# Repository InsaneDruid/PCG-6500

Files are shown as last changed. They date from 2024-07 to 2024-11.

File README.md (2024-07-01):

# PCG 6500 - a HAL clone
The PCG 6500 is a 100% compatible clone of the programmable character set generator and sound device for the CBM PET series computers.
It implements all the features, including the ability to reprogram 64 of the PET characters into custom graphics, as well as support for amplified CB2 sound output.

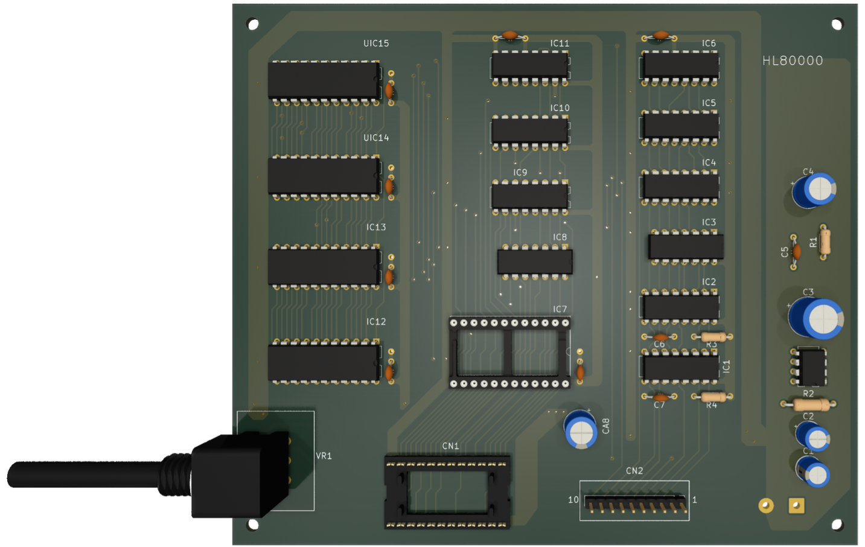
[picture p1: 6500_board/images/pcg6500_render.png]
PCG6500 render


[Schematic](https://github.com/InsaneDruid/PCG-6500/blob/main/6500_board/pcg6500.pdf "Schematic")  

[Bill of Materials](https://htmlpreview.github.io/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 "Bill of Materials")

## The 6540 Adapter
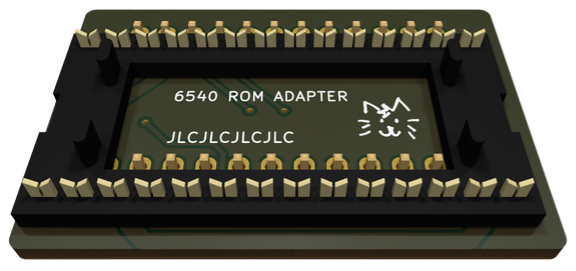
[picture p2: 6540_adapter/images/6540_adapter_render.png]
6540 Adapter render


For PETs using the MOS 6540 rom set, there is an [adapter board](https://github.com/InsaneDruid/PCG-6500/blob/main/6540_adapter "adapter board") that mounts in place of CN1 and allows easy connection to the 6540 charrom using two DIP 28pin to ribbon adapters.

## The SwitchMod
Originally, there was no way to simply disable the HAL PCG 6500 once installed. Katunori Takesita discovered a simple modification that an owner had applied to his board, which consisted of disconnecting an input of a nand-gate from address 9 of the CharROM bus (by cutting a trace) and grounding it instead, effectively disabling the RAM and re-enabling the CharROM permanently. This mod is also implemented in this replica and jumper JP1 is provided for this purpose.

### Enabling the card permanently
Bridge JP1 to permanently enable the card like it was originally.

### The SwitchMod board
A small [SwitchMod board](https://github.com/InsaneDruid/PCG-6500/blob/main/6500_switchMod "SwitchMod board") has been designed providing the ability to switch between the address9 signal and GND for the input of IC8D using an 74LS00, avoiding the need to route the fast address signal over a mechanical switch. This board also has the ability to connect a 3-pin common cathode dual LED (or one or two standard LEDs) to indicate the state of the board. Connect the pins E,A,+,- on the SwitchMod to the corresponding pins on the 6500 board.

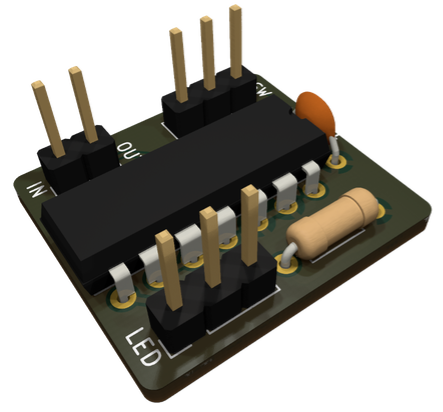
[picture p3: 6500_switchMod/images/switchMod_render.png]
SwitchMod board render


## The case
A [3d printable case](https://www.printables.com/model/819722-hal-pcg-6500-case "https://www.printables.com/model/819722-hal-pcg-6500-case") is available at my printables profile.
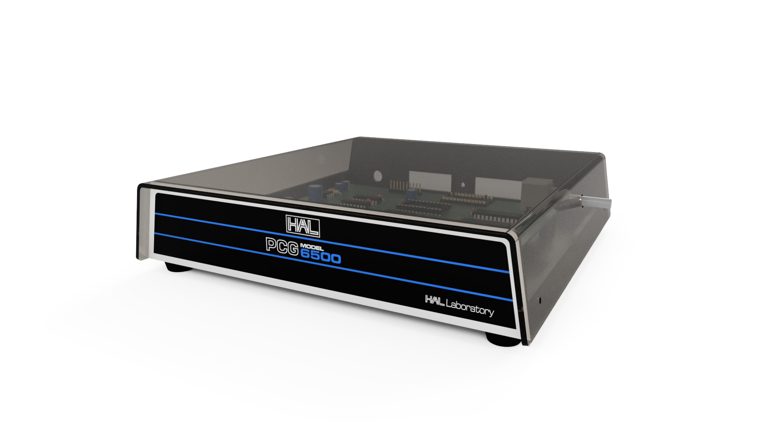
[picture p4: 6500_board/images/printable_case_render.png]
printable case render


## Programming the PCG 6500 
Each programmable character provided by the PCG 6500 is programmed line by line via the PETs 6522 peripheral port A (PA7-0), which is available on the user port. PA0-4 transport the actual data, PA 5-7 address the data and address latches on the PCG 6500
See the [Programming chart](https://github.com/InsaneDruid/PCG-6500/blob/main/6500_programming_chart.pdf "Programming chart") originally taken from the PCG 6500 manual with some fixed typos.

## The Software
Software using the PCG-6500 and further documents are available on their own repository: [PCG-6500 Software](https://github.com/InsaneDruid/PCG-6500-Software "Software and Documents for the PCG-6500 Software")

## The License
This work is licensed under a Creative Commons Attribution-ShareAlike 4.0 International License.  
See https://creativecommons.org/licenses/by-sa/4.0/.

## The Credits
This work would not have been possible without the help from a bunch of amazing people from [VzEkC e. V. forums](https://forum.classic-computing.de/forum/ "forum.classic-computing.de") and around the world. Many thanks go out to:

* *AndyG* - for providing images of a working board.
* *Katunori Takesita* - his blog about repairing an original board had important additional images and informations.

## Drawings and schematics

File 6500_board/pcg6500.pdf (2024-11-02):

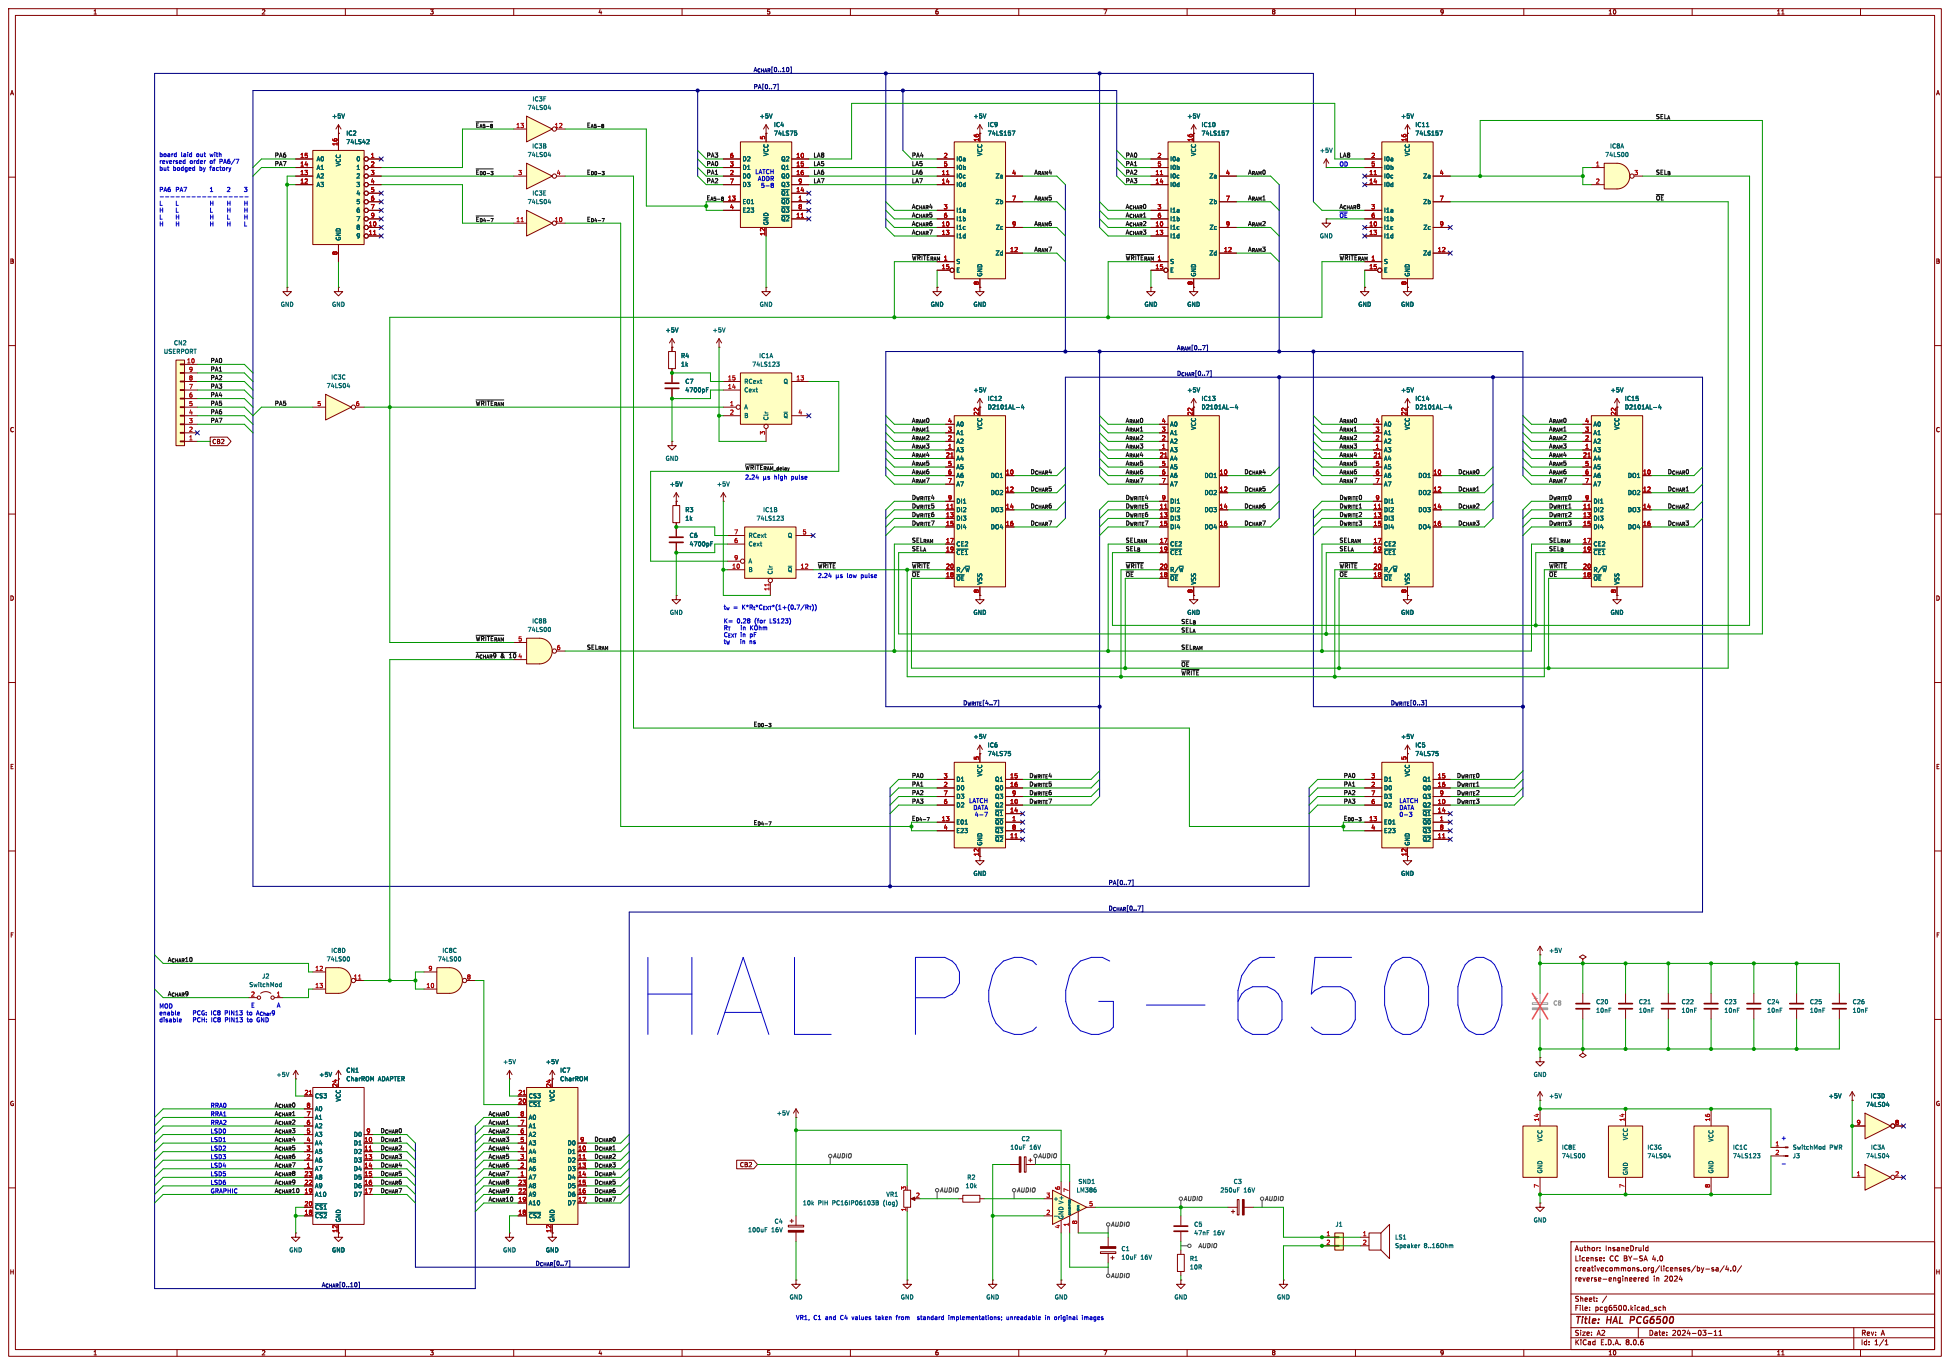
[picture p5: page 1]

board laid out with
reversed order of PA6/7

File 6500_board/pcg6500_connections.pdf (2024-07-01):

# HAL PCG-6500 wire connections

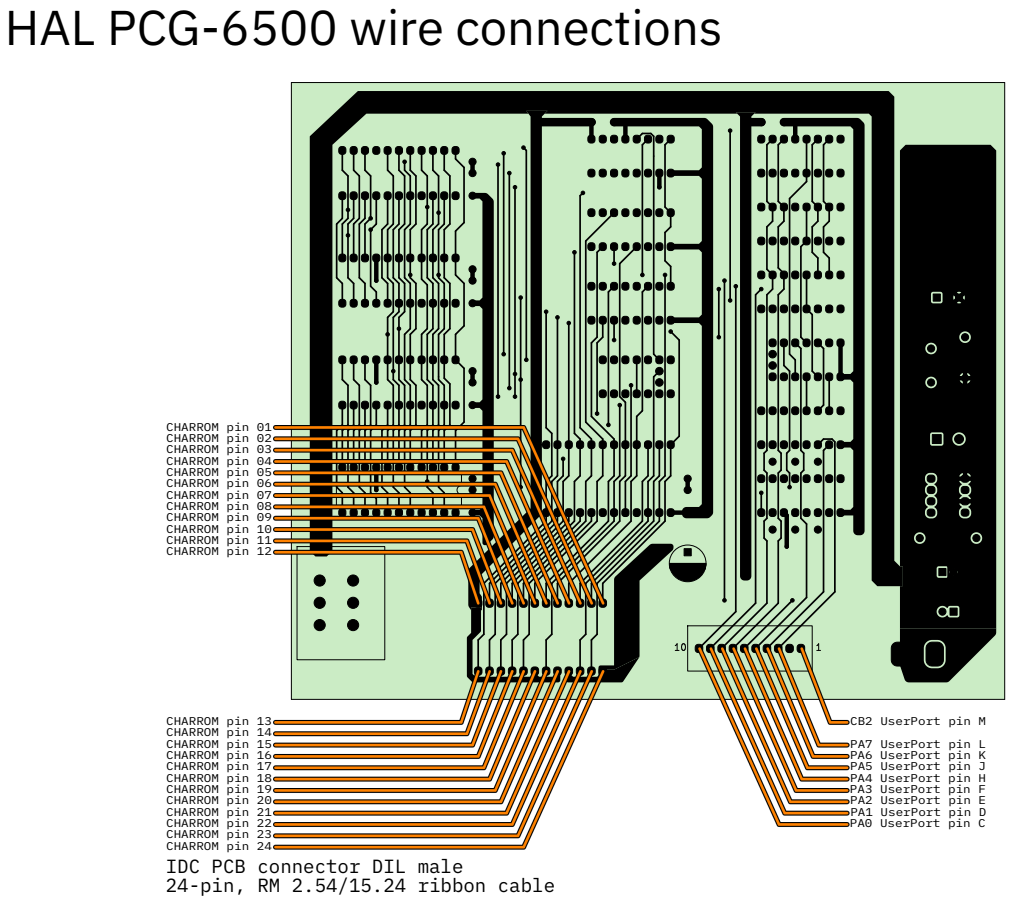
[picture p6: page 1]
CHARROM pin 12; CHARROM pin 11; CHARROM pin 10; CHARROM pin 08; CHARROM pin 07; CHARROM pin 06; CHARROM pin 05; CHARROM pin 04; CHARROM pin 03; CHARROM pin 02; CHARROM pin 01; CHARROM pin 09; PA0 UserPort pin C; PA1 UserPort pin D; PA2 UserPort pin E; PA4 UserPort pin H; PA5 UserPort pin J; PA6 UserPort pin K; PA7 UserPort pin L; CB2 UserPort pin M; PA3 UserPort pin F

CHARROM pin 13
CHARROM pin 14
CHARROM pin 15
CHARROM pin 16
CHARROM pin 17
CHARROM pin 18
CHARROM pin 19
CHARROM pin 20
CHARROM pin 21
CHARROM pin 22
CHARROM pin 23
CHARROM pin 24
IDC PCB connector DIL male
24-pin, RM 2.54/15.24 ribbon cable

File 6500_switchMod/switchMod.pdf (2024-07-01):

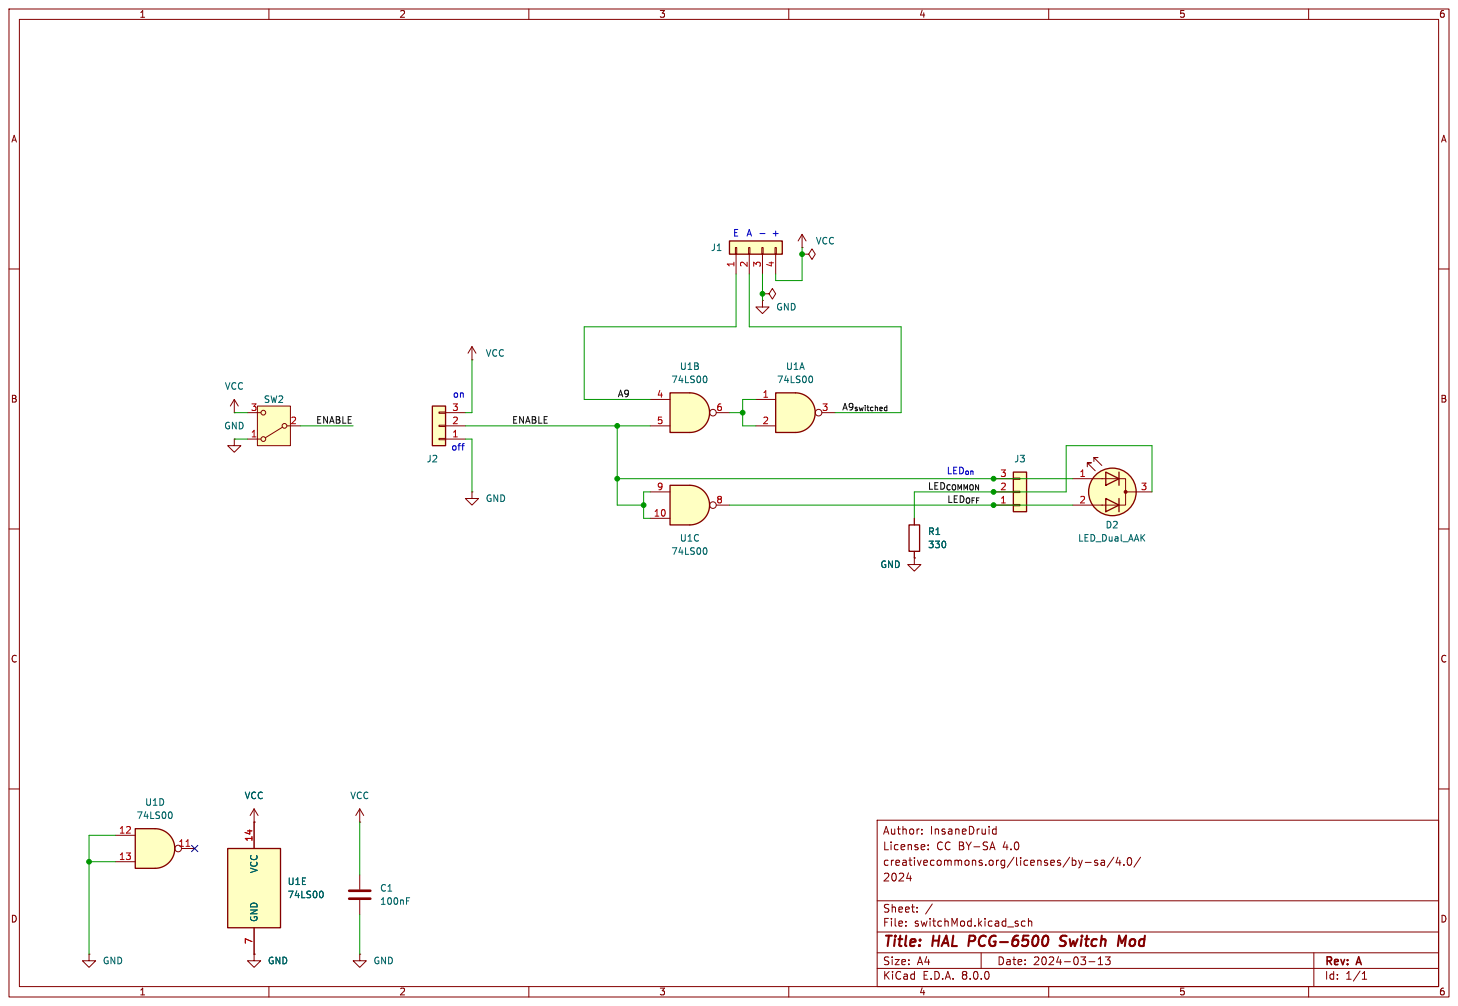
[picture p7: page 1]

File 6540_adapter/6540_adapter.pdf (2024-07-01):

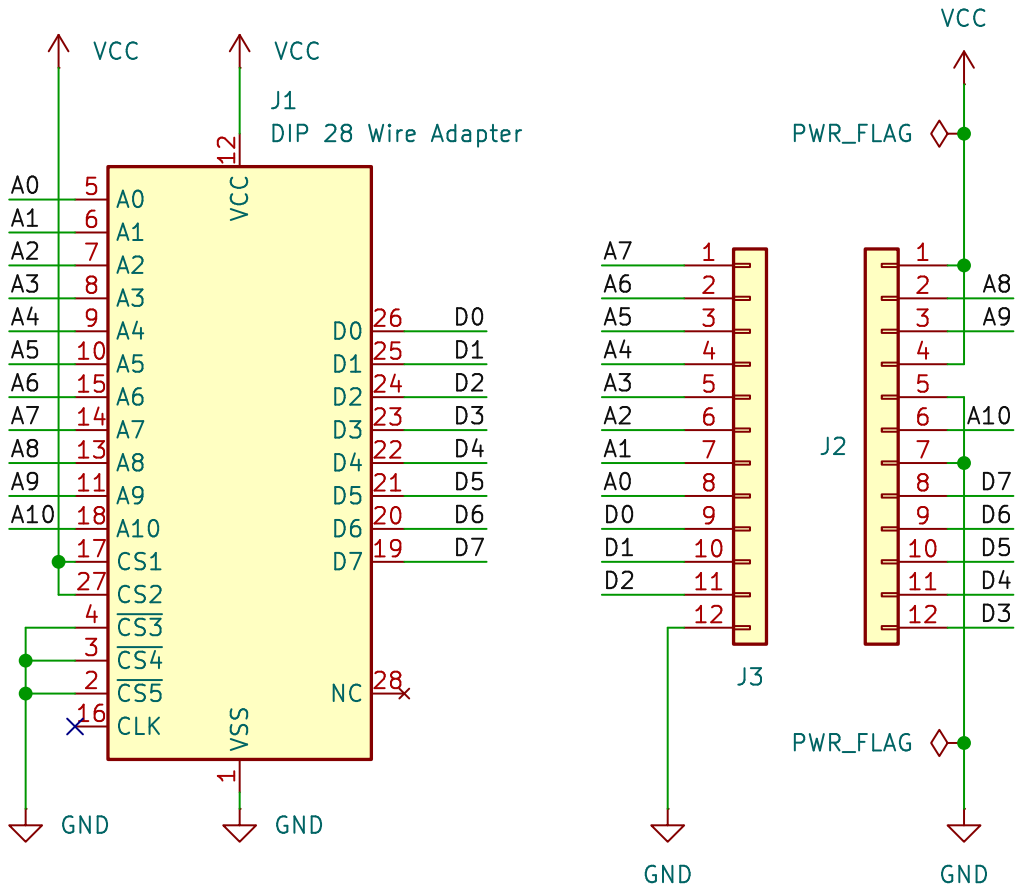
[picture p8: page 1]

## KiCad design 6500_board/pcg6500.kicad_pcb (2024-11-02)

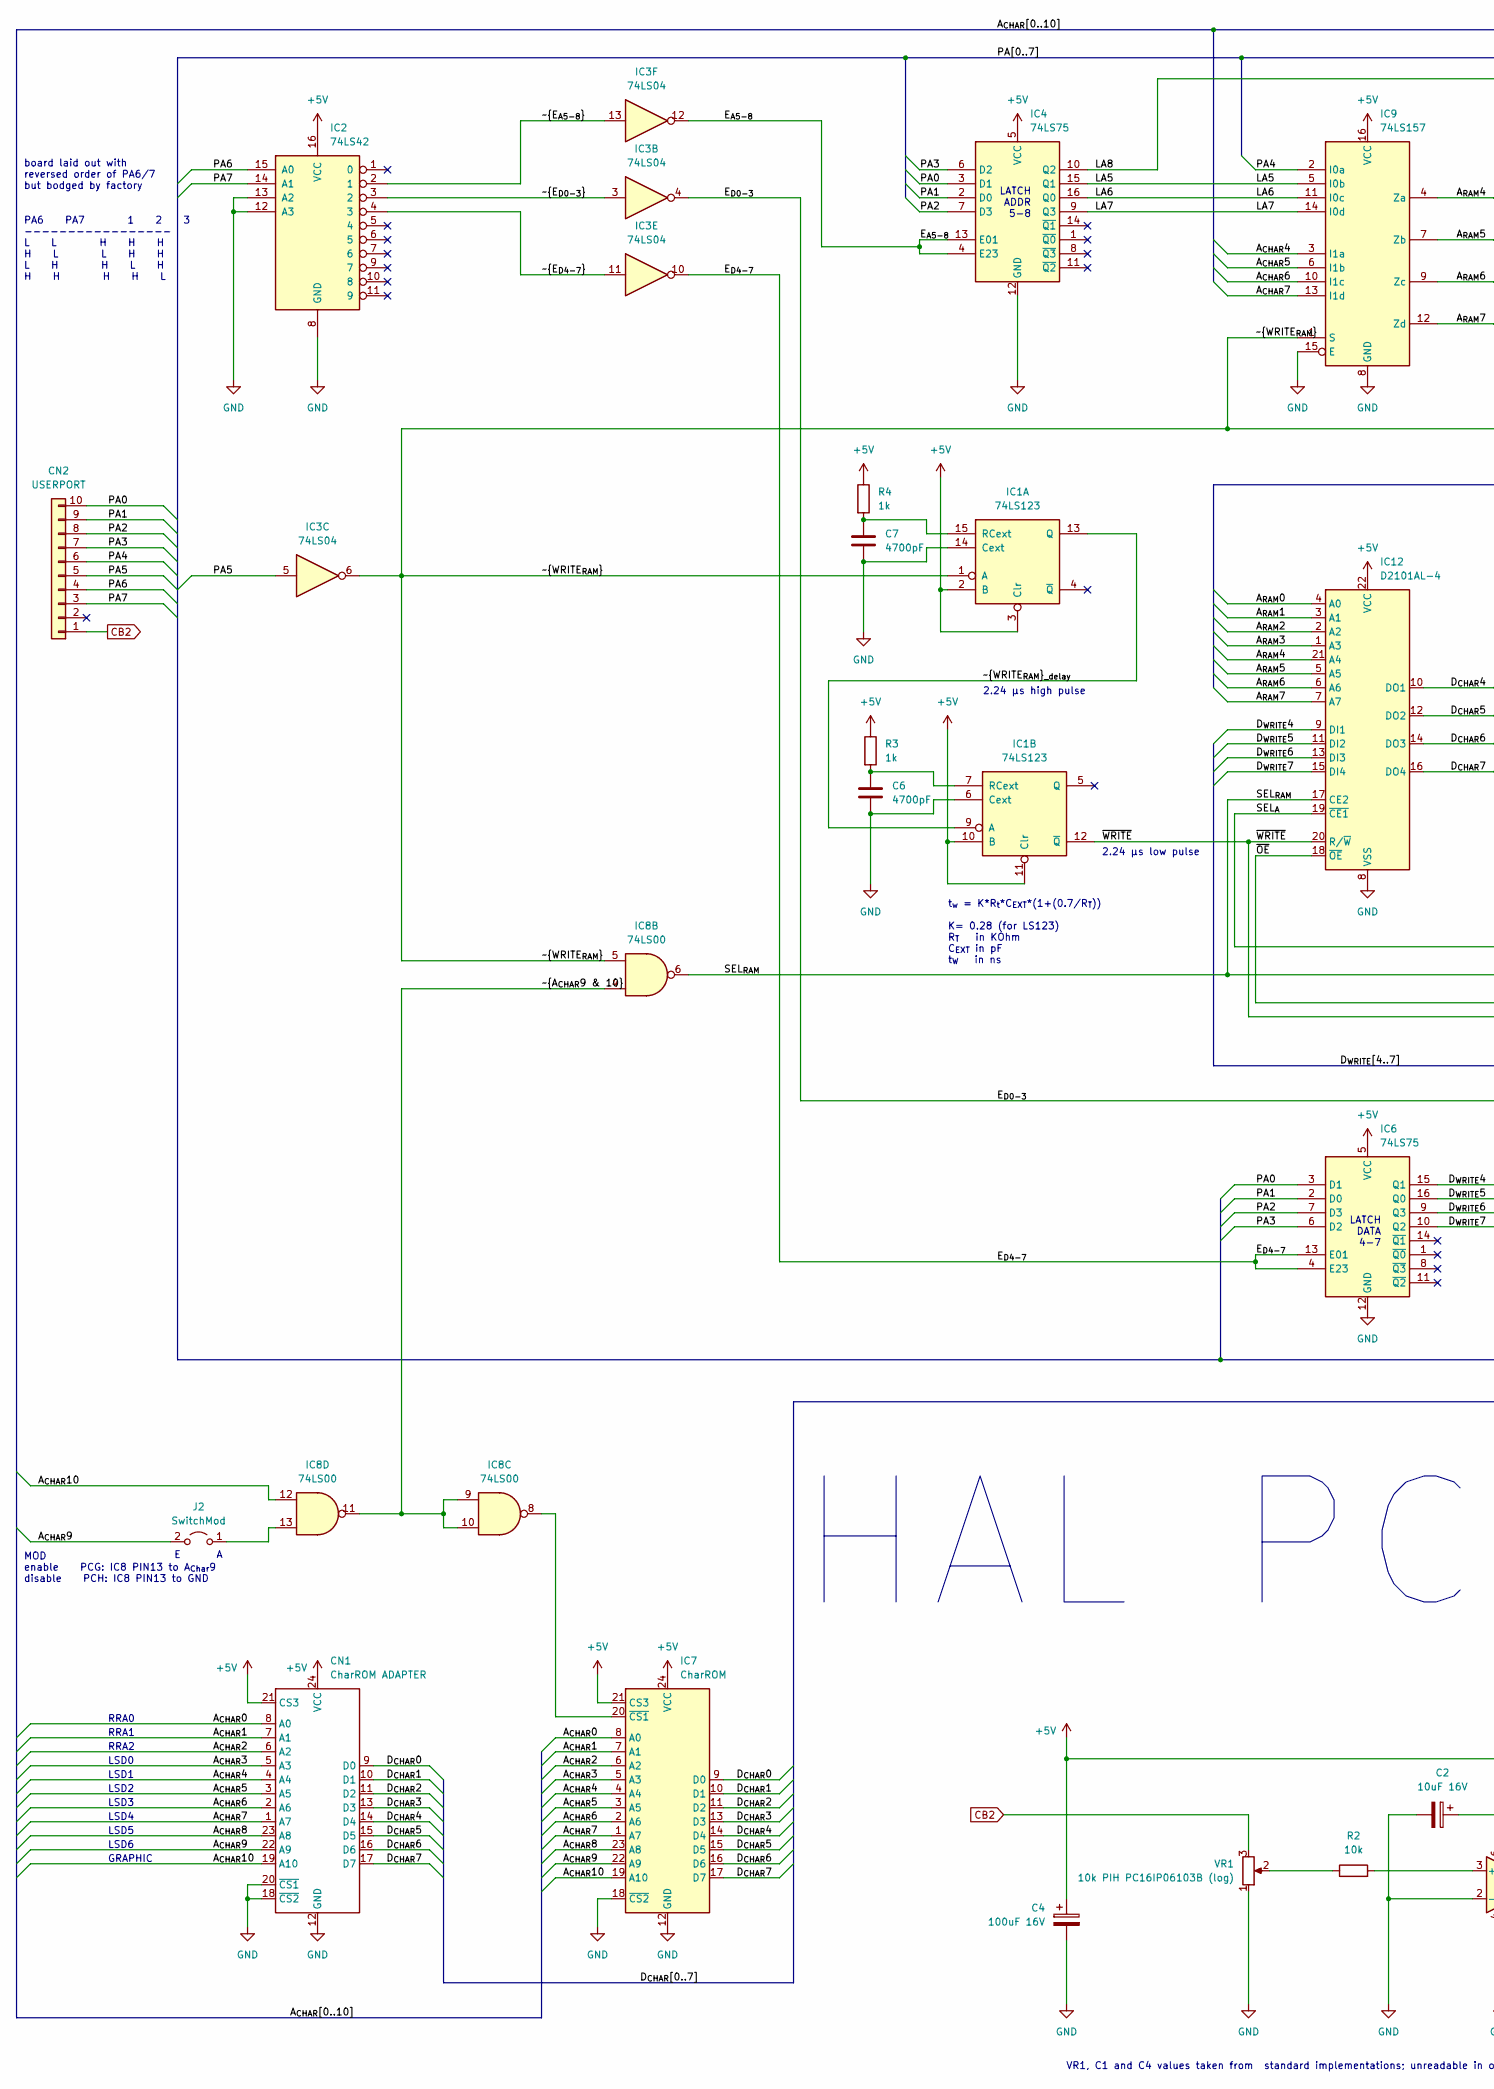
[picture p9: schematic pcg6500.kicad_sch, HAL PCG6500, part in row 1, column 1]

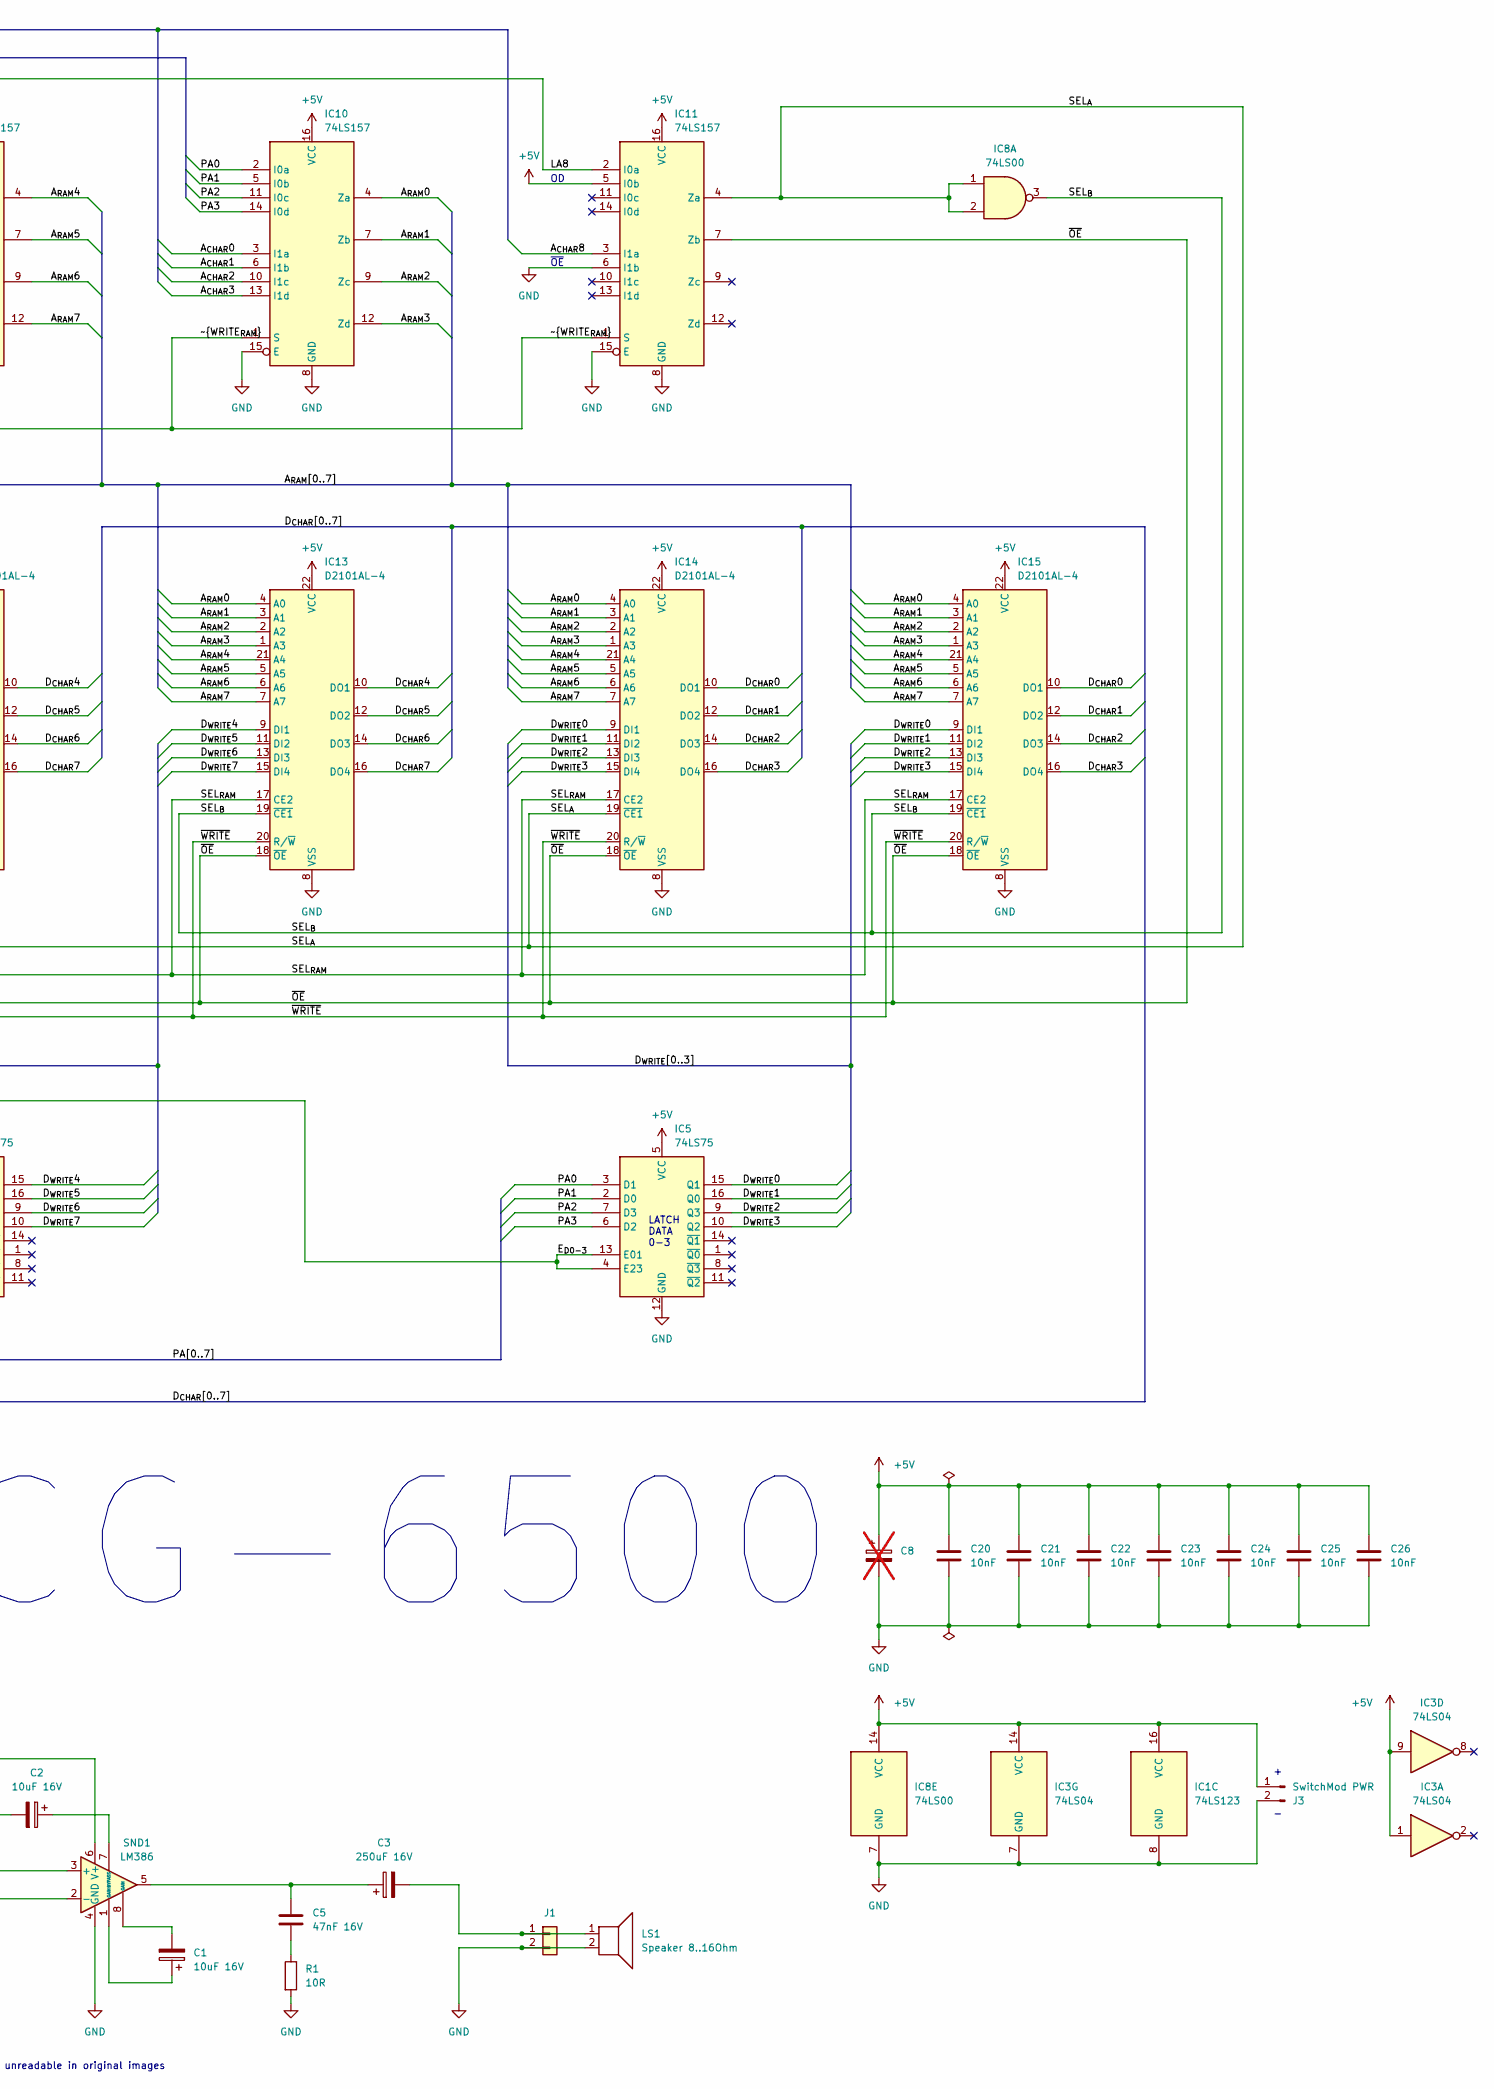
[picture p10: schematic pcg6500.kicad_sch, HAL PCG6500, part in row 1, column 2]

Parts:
C1, C2: 10uF 16V; CP_Radial_D6.3mm_P2.50mm
C3: 250uF 16V; CP_Radial_D10.0mm_P5.00mm
C4: 100uF 16V; CP_Radial_D8.0mm_P5.00mm
C5: 47nF 16V; C_Disc_D4.3mm_W1.9mm_P7.62mm
C6, C7: 4700pF; C_Disc_D4.3mm_W1.9mm_P5.08mm
C8: C_Polarized; CP_Radial_D8.0mm_P5.00mm; not fitted
C20, C21, C22, C23, C24, C25, C26: 10nF; C_Disc_D4.3mm_W1.9mm_P5.08mm_dualpad
CN1: CharROM ADAPTER; DIP-24_W15.24mm_Wire_Adapter
CN2: USERPORT; PinHeader_1x10_P2.54mm_Vertical
IC1: 74LS123; DIP-16_W7.62mm
IC2: 74LS42; DIP-16_W7.62mm
IC3: 74LS04; DIP-14_W7.62mm
IC4, IC5, IC6: 74LS75; DIP-16_W7.62mm
IC7: CharROM; DIP-24_W15.24mm_Socket
IC8: 74LS00; DIP-14_W7.62mm
IC9, IC10, IC11: 74LS157; DIP-16_W7.62mm
IC12, IC13, IC14, IC15: D2101AL-4; DIP-22_W10.16mm
J1: Speaker 8..16Ohm; SolderWire-1sqmm_1x02_P7.8mm_D1.4mm_OD3.9mm
J2: SwitchMod; PinHeader_1x02_P2.54mm_Horizontal
J3: SwitchMod PWR; PinHeader_1x02_P2.54mm_Horizontal
LS1: Speaker 8..16Ohm
R1: 10R; R_Axial_DIN0207_L6.3mm_D2.5mm_P9.2075mm_Horizontal
R2: 10k; R_Axial_DIN0309_L9.0mm_D3.2mm_P12.70mm_Horizontal
R3, R4: 1k; R_Axial_DIN0207_L6.3mm_D2.5mm_P9.2075mm_Horizontal
SND1: LM386; DIP-8_W7.62mm
VR1: 10k PIH PC16IP06103B (log); Potentiometer_Piher_PC-16_Dual_Horizontal

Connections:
+5V: C4.1, C8.1, C20.1, C21.1, C22.1, C23.1, C24.1, C25.2, C26.2, CN1.21 (CS3), CN1.24 (VCC), IC1.2 (B), IC1.3 (Clr), IC1.10 (B), IC1.11 (Clr), IC1.16 (VCC), IC2.16 (VCC), IC3.1, IC3.9, IC3.14 (VCC), IC4.5 (VCC), IC5.5 (VCC), IC6.5 (VCC), IC7.21 (CS3), IC7.24 (VCC), IC8.14 (VCC), IC9.16 (VCC), IC10.16 (VCC), IC11.5 (I0b), IC11.16 (VCC), IC12.22 (VCC), IC13.22 (VCC), IC14.22 (VCC), IC15.22 (VCC), J3.1, R3.1, R4.1, SND1.6 (V+)
/A_{CHAR}0: CN1.8 (A0), IC7.8 (A0), IC10.3 (I1a)
/A_{CHAR}1: CN1.7 (A1), IC7.7 (A1), IC10.6 (I1b)
/A_{CHAR}2: CN1.6 (A2), IC7.6 (A2), IC10.10 (I1c)
/A_{CHAR}3: CN1.5 (A3), IC7.5 (A3), IC10.13 (I1d)
/A_{CHAR}4: CN1.4 (A4), IC7.4 (A4), IC9.3 (I1a)
/A_{CHAR}5: CN1.3 (A5), IC7.3 (A5), IC9.6 (I1b)
/A_{CHAR}6: CN1.2 (A6), IC7.2 (A6), IC9.10 (I1c)
/A_{CHAR}7: CN1.1 (A7), IC7.1 (A7), IC9.13 (I1d)
/A_{CHAR}8: CN1.23 (A8), IC7.23 (A8), IC11.3 (I1a)
/A_{CHAR}9: CN1.22 (A9), IC7.22 (A9), J2.2 (B)
/A_{CHAR}10: CN1.19 (A10), IC7.19 (A10), IC8.12
/A_{RAM}0: IC10.4 (Za), IC12.4 (A0), IC13.4 (A0), IC14.4 (A0), IC15.4 (A0)
/A_{RAM}1: IC10.7 (Zb), IC12.3 (A1), IC13.3 (A1), IC14.3 (A1), IC15.3 (A1)
/A_{RAM}2: IC10.9 (Zc), IC12.2 (A2), IC13.2 (A2), IC14.2 (A2), IC15.2 (A2)
/A_{RAM}3: IC10.12 (Zd), IC12.1 (A3), IC13.1 (A3), IC14.1 (A3), IC15.1 (A3)
/A_{RAM}4: IC9.4 (Za), IC12.21 (A4), IC13.21 (A4), IC14.21 (A4), IC15.21 (A4)
/A_{RAM}5: IC9.7 (Zb), IC12.5 (A5), IC13.5 (A5), IC14.5 (A5), IC15.5 (A5)
/A_{RAM}6: IC9.9 (Zc), IC12.6 (A6), IC13.6 (A6), IC14.6 (A6), IC15.6 (A6)
/A_{RAM}7: IC9.12 (Zd), IC12.7 (A7), IC13.7 (A7), IC14.7 (A7), IC15.7 (A7)
/D_{CHAR}0: CN1.9 (D0), IC7.9 (D0), IC14.10 (DO1), IC15.10 (DO1)
/D_{CHAR}1: CN1.10 (D1), IC7.10 (D1), IC14.12 (DO2), IC15.12 (DO2)
/D_{CHAR}2: CN1.11 (D2), IC7.11 (D2), IC14.14 (DO3), IC15.14 (DO3)
/D_{CHAR}3: CN1.13 (D3), IC7.13 (D3), IC14.16 (DO4), IC15.16 (DO4)
/D_{CHAR}4: CN1.14 (D4), IC7.14 (D4), IC12.10 (DO1), IC13.10 (DO1)
/D_{CHAR}5: CN1.15 (D5), IC7.15 (D5), IC12.12 (DO2), IC13.12 (DO2)
/D_{CHAR}6: CN1.16 (D6), IC7.16 (D6), IC12.14 (DO3), IC13.14 (DO3)
/D_{CHAR}7: CN1.17 (D7), IC7.17 (D7), IC12.16 (DO4), IC13.16 (DO4)
/D_{WRITE}0: IC5.15 (Q1), IC14.9 (DI1), IC15.9 (DI1)
/D_{WRITE}1: IC5.16 (Q0), IC14.11 (DI2), IC15.11 (DI2)
/D_{WRITE}2: IC5.9 (Q3), IC14.13 (DI3), IC15.13 (DI3)
/D_{WRITE}3: IC5.10 (Q2), IC14.15 (DI4), IC15.15 (DI4)
/D_{WRITE}4: IC6.15 (Q1), IC12.9 (DI1), IC13.9 (DI1)
/D_{WRITE}5: IC6.16 (Q0), IC12.11 (DI2), IC13.11 (DI2)
/D_{WRITE}6: IC6.9 (Q3), IC12.13 (DI3), IC13.13 (DI3)
/D_{WRITE}7: IC6.10 (Q2), IC12.15 (DI4), IC13.15 (DI4)
/E_{A5-8}: IC3.12, IC4.4 (E23), IC4.13 (E01)
/E_{D0-3}: IC3.4, IC5.4 (E23), IC5.13 (E01)
/E_{D4-7}: IC3.10, IC6.4 (E23), IC6.13 (E01)
/LA5: IC4.15 (Q1), IC9.5 (I0b)
/LA6: IC4.16 (Q0), IC9.11 (I0c)
/LA7: IC4.9 (Q3), IC9.14 (I0d)
/LA8: IC4.10 (Q2), IC11.2 (I0a)
/PA0: CN2.10, IC4.3 (D1), IC5.3 (D1), IC6.3 (D1), IC10.2 (I0a)
/PA1: CN2.9, IC4.2 (D0), IC5.2 (D0), IC6.2 (D0), IC10.5 (I0b)
/PA2: CN2.8, IC4.7 (D3), IC5.7 (D3), IC6.7 (D3), IC10.11 (I0c)
/PA3: CN2.7, IC4.6 (D2), IC5.6 (D2), IC6.6 (D2), IC10.14 (I0d)
/PA4: CN2.6, IC9.2 (I0a)
/PA5: CN2.5, IC3.5
/PA6: CN2.4, IC2.15 (A0)
/PA7: CN2.3, IC2.14 (A1)
/SEL_{A}: IC8.1, IC8.2, IC11.4 (Za), IC12.19 (~CE1), IC14.19 (~CE1)
/SEL_{B}: IC8.3, IC13.19 (~CE1), IC15.19 (~CE1)
/SEL_{RAM}: IC8.6, IC12.17 (CE2), IC13.17 (CE2), IC14.17 (CE2), IC15.17 (CE2)
/~A_{CHAR9 & 10}: IC8.4, IC8.9, IC8.10, IC8.11
/~E_{A5-8}: IC2.2 (1), IC3.13
/~E_{D0-3}: IC2.3 (2), IC3.3
/~E_{D4-7}: IC2.4 (3), IC3.11
/~OE: IC11.7 (Zb), IC12.18 (~OE), IC13.18 (~OE), IC14.18 (~OE), IC15.18 (~OE)
/~WRITE_{RAM}: IC1.1 (A), IC3.6, IC8.5, IC9.1 (S), IC10.1 (S), IC11.1 (S)
/~WRITE_{RAM}_{_delay}: IC1.9 (A), IC1.13 (Q)
/~WRITE: IC1.12 (~Q), IC12.20 (R/~W), IC13.20 (R/~W), IC14.20 (R/~W), IC15.20 (R/~W)
CB2: CN2.1, VR1.3
GND: C2.2, C4.2, C6.2, C7.2, C8.2, C20.2, C21.2, C22.2, C23.2, C24.2, C25.1, C26.1, CN1.12 (GND), CN1.18 (~CS2), CN1.20 (~CS1), IC1.6 (Cext), IC1.8 (GND), IC1.14 (Cext), IC2.8 (GND), IC2.12 (A3), IC2.13 (A2), IC3.7 (GND), IC4.12 (GND), IC5.12 (GND), IC6.12 (GND), IC7.12 (GND), IC7.18 (~CS2), IC8.7 (GND), IC9.8 (GND), IC9.15 (E), IC10.8 (GND), IC10.15 (E), IC11.6 (I1b), IC11.8 (GND), IC11.15 (E), IC12.8 (VSS), IC13.8 (VSS), IC14.8 (VSS), IC15.8 (VSS), J1.2, J1.12, J1.18, J1.20, J3.2, LS1.2, R1.2, SND1.2 (-), SND1.4 (GND), VR1.1
unnamed: C1.1, SND1.1 (GAIN)
unnamed: C1.2, SND1.8 (GAIN)
unnamed: C3.1, C5.1, SND1.5
unnamed: C5.2, R1.1
unnamed: C7.1, IC1.15 (RCext), R4.2
unnamed: C6.1, IC1.7 (RCext), R3.2
unnamed: IC7.20 (~CS1), IC8.8
unnamed: C3.2, J1.1, LS1.1
unnamed: IC8.13, J2.1 (A)
unnamed: R2.1, VR1.2
unnamed: R2.2, SND1.3 (+)
unnamed: C2.1, SND1.7 (BYPASS)

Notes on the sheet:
LATCH DATA 4-7
board laid out with reversed order of PA6/7 but bodged by factory
LATCH DATA 0-3
LSD2
LATCH ADDR 5-8
2.24 µs low pulse
t_{w} = K*R_{t}*C_{EXT}*(1+(0.7/R_{T})) K= 0.28 (for LS123) R_{T} in KOhm C_{EXT} in pF t_{W} in ns
RRA2
RRA1
GRAPHIC
LSD1
RRA0
LSD0
2.24 µs high pulse
HAL PCG-6500
LSD6
LSD3
LSD5
~{OE}
MOD enable PCG: IC8 PIN13 to A_{Char}9 disable PCH: IC8 PIN13 to GND
LSD4
VR1, C1 and C4 values taken from standard implementations; unreadable in original images
PA6 PA7 1 2 3 ----------------- L L H H H H L L H H L H H L H H H H H L

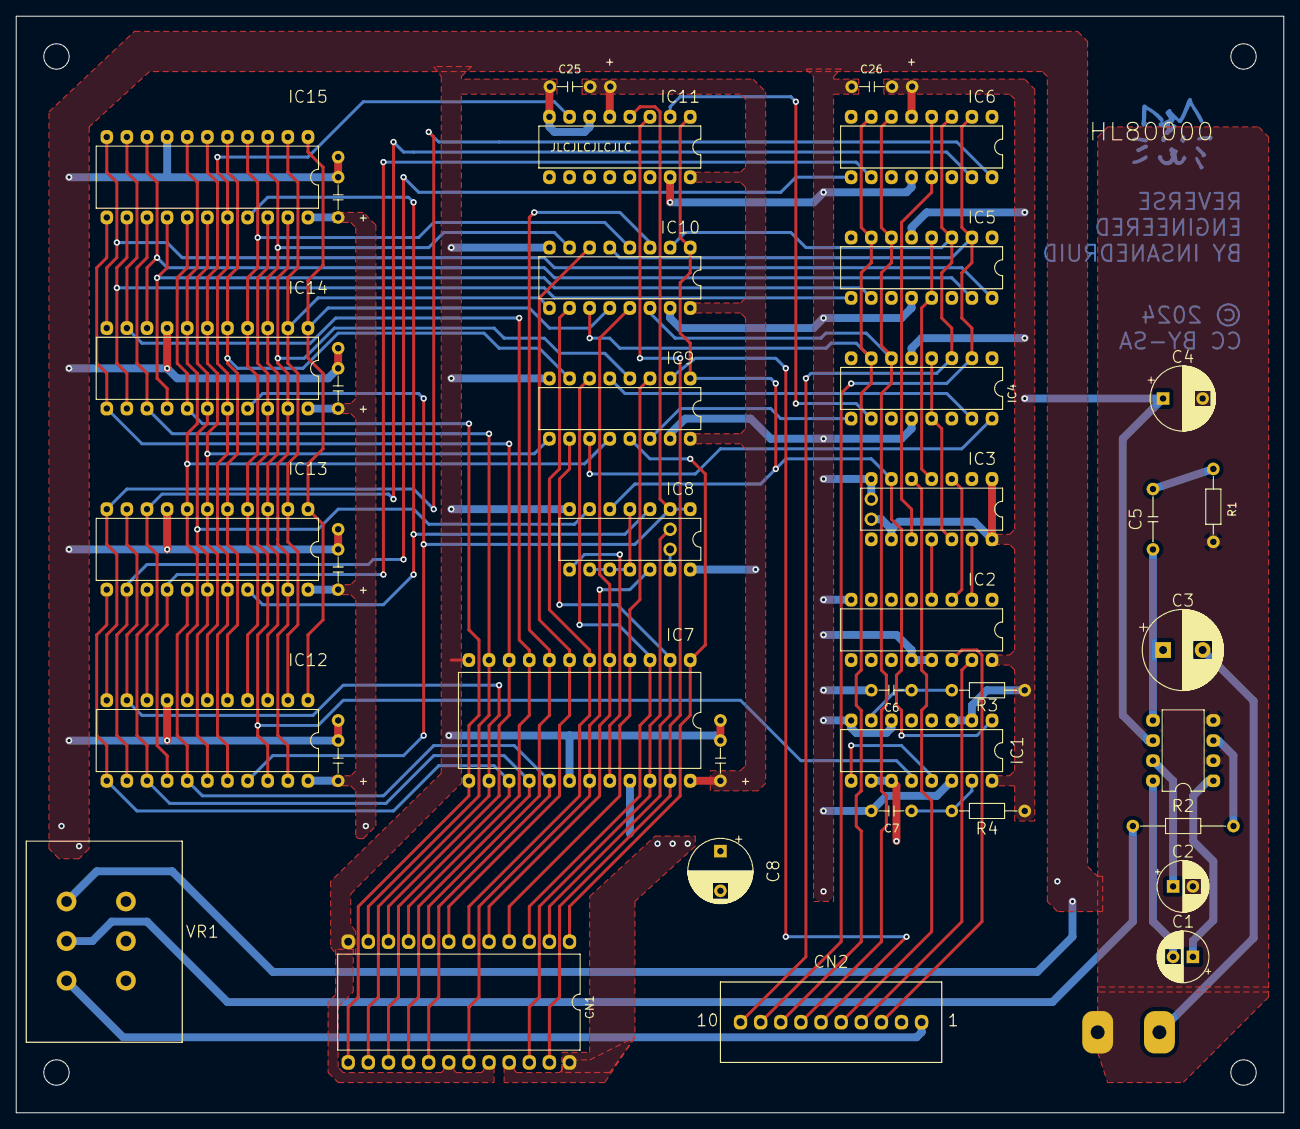
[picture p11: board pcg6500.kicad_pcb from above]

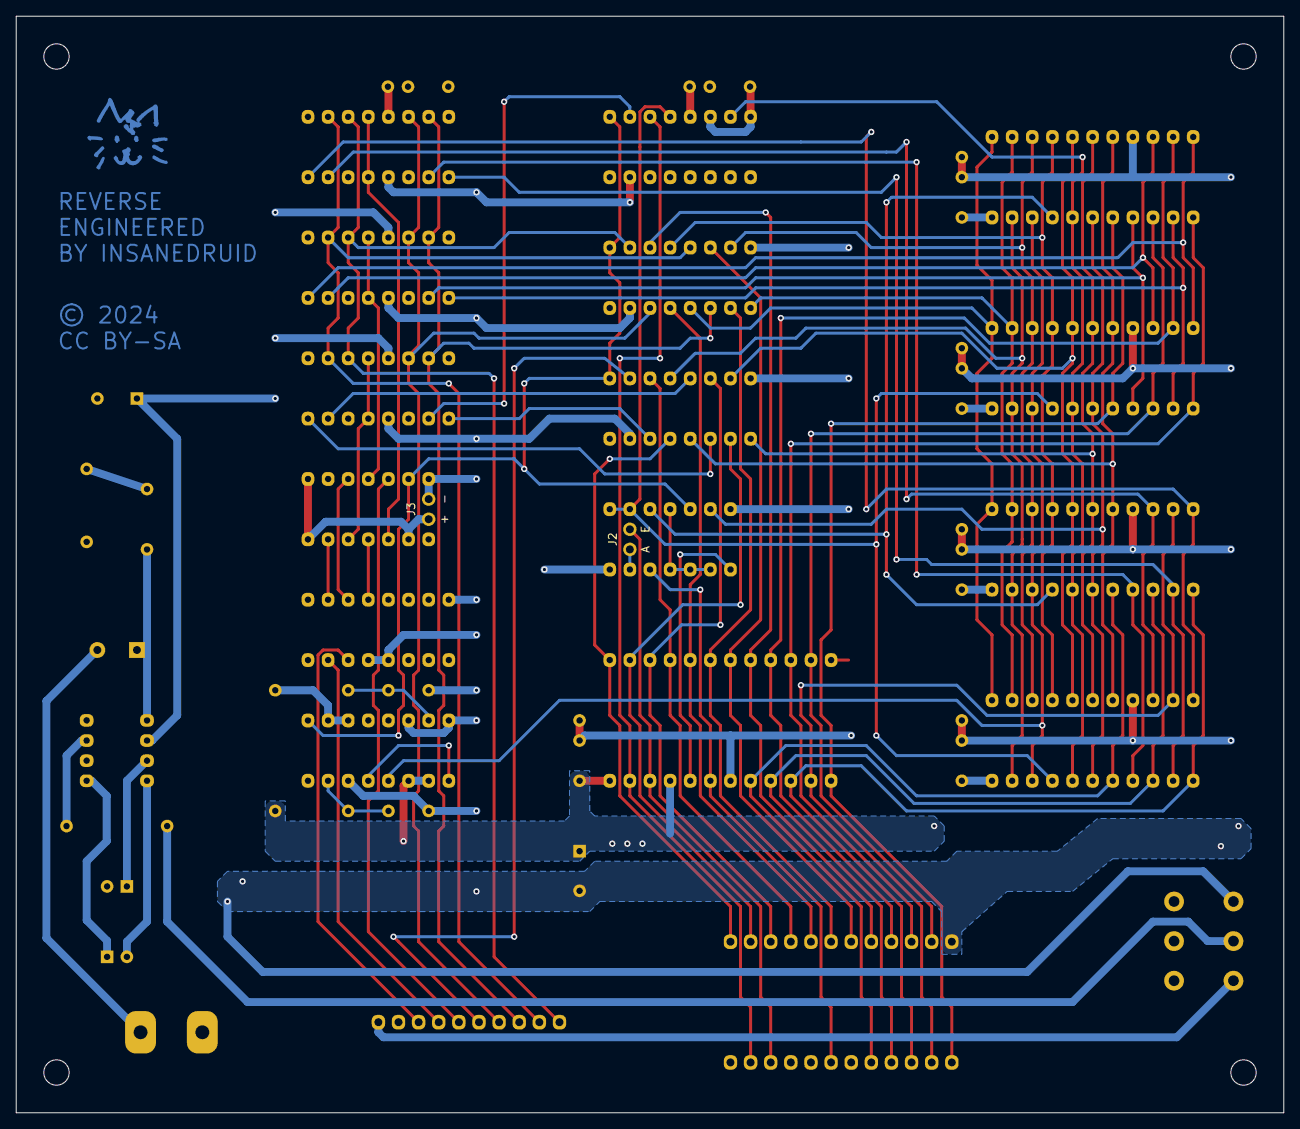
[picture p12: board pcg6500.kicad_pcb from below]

Board: 2 copper layers, 160.0 x 138.4 mm, 45 parts (2 on the bottom side), 76 nets.

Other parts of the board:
Mountinghole_BL: MountingHole_3.2mm_M3_DIN965
Mountinghole_BR: MountingHole_3.2mm_M3_DIN965
Mountinghole_TL: MountingHole_3.2mm_M3_DIN965
Mountinghole_TR: MountingHole_3.2mm_M3_DIN965

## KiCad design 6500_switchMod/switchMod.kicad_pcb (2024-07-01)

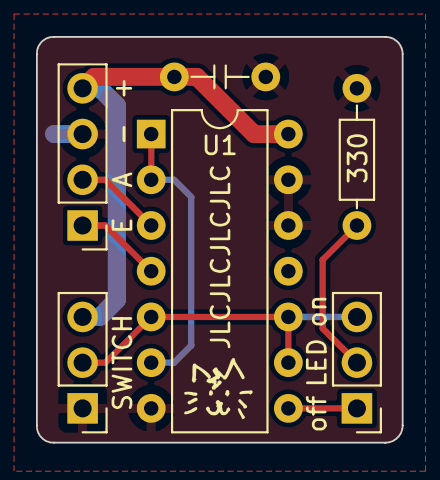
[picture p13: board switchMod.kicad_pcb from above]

Board: 2 copper layers, 20.3 x 22.5 mm, 6 parts (0 on the bottom side), 8 nets.

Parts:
C1: 100nF; C_Disc_D4.3mm_W1.9mm_P5.08mm
J1: 6500 Connector; PinHeader_1x04_P2.54mm_Vertical
J2: Switch Connector; PinHeader_1x03_P2.54mm_Vertical
J3: LED Connector; PinHeader_1x03_P2.54mm_Vertical
R1: 330R; R_Axial_DIN0207_L6.3mm_D2.5mm_P7.62mm_Horizontal
U1: 74LS00; DIP-14_W7.62mm

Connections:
/A9: J1.1, U1.4
/A9_{switched}: J1.2, U1.3
/ENABLE: J2.2, J3.3, U1.5, U1.9, U1.10
/LED_{COMMON}: J3.2, R1.2
/LED_{OFF}: J3.1, U1.8
GND: C1.2, J1.3, J2.1, R1.1, U1.7 (GND), U1.12, U1.13
unnamed: U1.1, U1.2, U1.6
VCC: C1.1, J1.4, J2.3, U1.14 (VCC)

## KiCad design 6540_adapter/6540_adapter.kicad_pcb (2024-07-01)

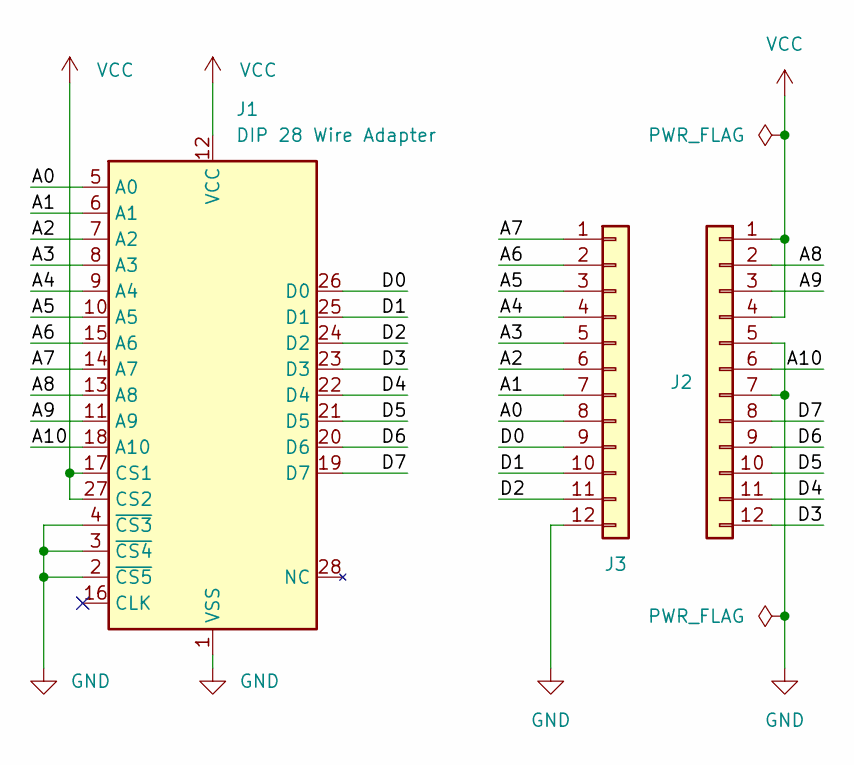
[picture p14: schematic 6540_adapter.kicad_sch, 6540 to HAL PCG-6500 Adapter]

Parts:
J1: DIP 28 Wire Adapter; DIP-28_W15.24mm_Wire_Adapter
J2, J3: Conn_01x12; PinHeader_1x12_P2.54mm_Vertical

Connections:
/A0: J1.5 (A0), J3.8
/A1: J1.6 (A1), J3.7
/A2: J1.7 (A2), J3.6
/A3: J1.8 (A3), J3.5
/A4: J1.9 (A4), J3.4
/A5: J1.10 (A5), J3.3
/A6: J1.15 (A6), J3.2
/A7: J1.14 (A7), J3.1
/A8: J1.13 (A8), J2.2
/A9: J1.11 (A9), J2.3
/A10: J1.18 (A10), J2.6
/D0: J1.26 (D0), J3.9
/D1: J1.25 (D1), J3.10
/D2: J1.24 (D2), J3.11
/D3: J1.23 (D3), J2.12
/D4: J1.22 (D4), J2.11
/D5: J1.21 (D5), J2.10
/D6: J1.20 (D6), J2.9
/D7: J1.19 (D7), J2.8
GND: J1.1 (VSS), J1.2 (~CS5), J1.3 (~CS4), J1.4 (~CS3), J2.5, J2.7, J3.12
VCC: J1.12 (VCC), J1.17 (CS1), J1.27 (CS2), J2.1, J2.4

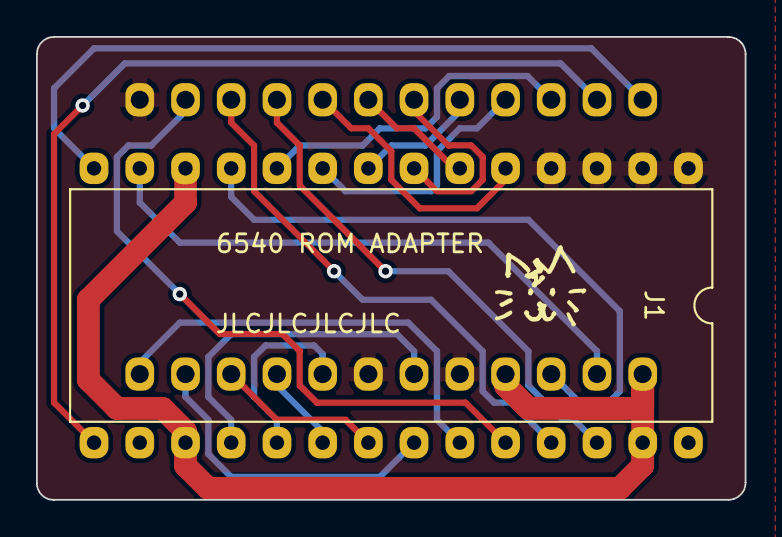
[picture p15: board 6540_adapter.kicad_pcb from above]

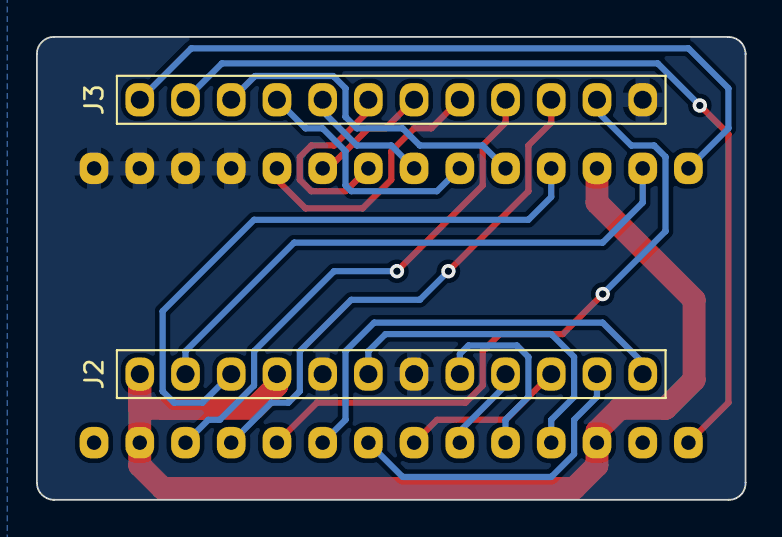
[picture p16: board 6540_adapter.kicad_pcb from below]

Board: 2 copper layers, 39.4 x 25.7 mm, 3 parts (2 on the bottom side), 21 nets.

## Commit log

2024-10-08 housekeeping
    added missing Cap values
    improvements in signal naming and schematic layout
    no functional changes
    [pcg6500.kicad_pcb, pcg6500.kicad_sch]
2024-11-02 BOM adjustment
    - changed excessive voltage rating of audio related capacitors to more realistic values
    - added cn2 connector to bom
    [pcg6500.kicad_pcb, pcg6500.kicad_sch]

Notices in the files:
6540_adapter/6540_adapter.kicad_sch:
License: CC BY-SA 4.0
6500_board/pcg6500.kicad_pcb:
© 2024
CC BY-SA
